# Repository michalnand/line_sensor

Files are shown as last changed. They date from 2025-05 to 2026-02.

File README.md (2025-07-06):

# i2c sensor for line follower

- 10x analog readed sensor
- stm32g031k8u6 64MHz arm cortex m0+ mcu
- i2c interface, with FFC cable
- uart, swdio availible for debug

# photos

TODO

# hardware basic

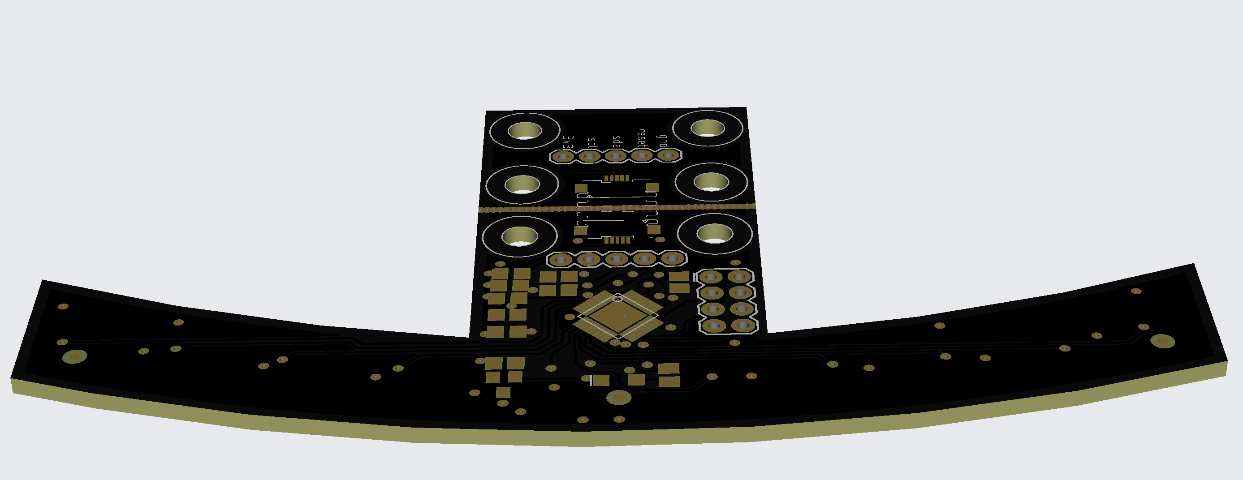
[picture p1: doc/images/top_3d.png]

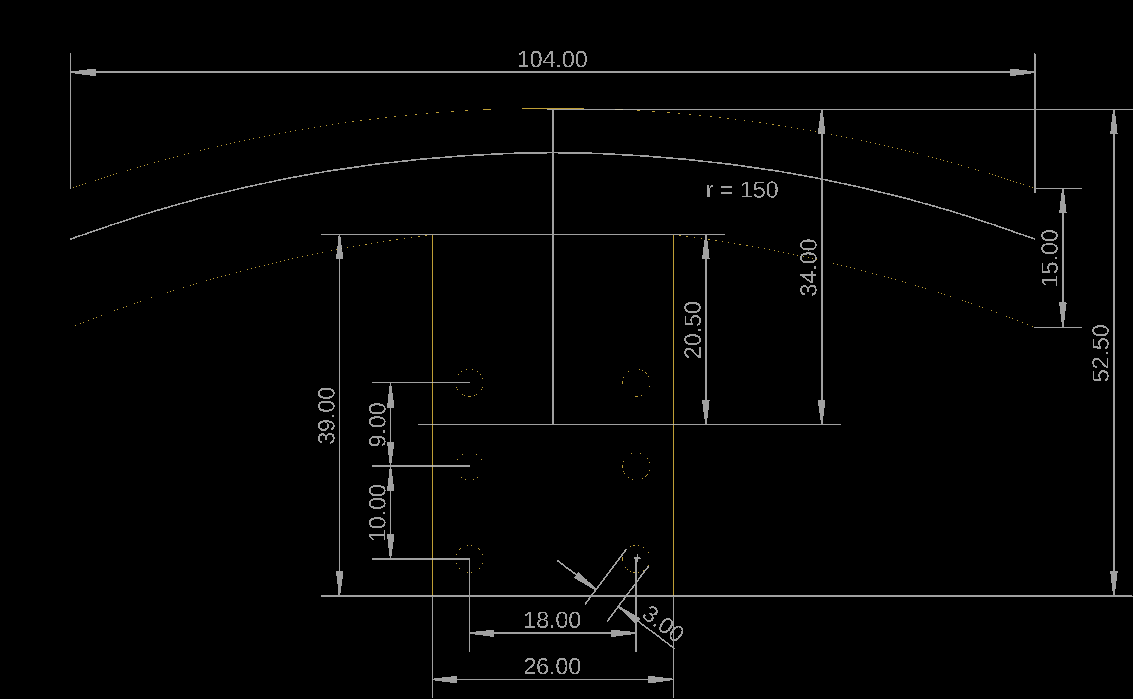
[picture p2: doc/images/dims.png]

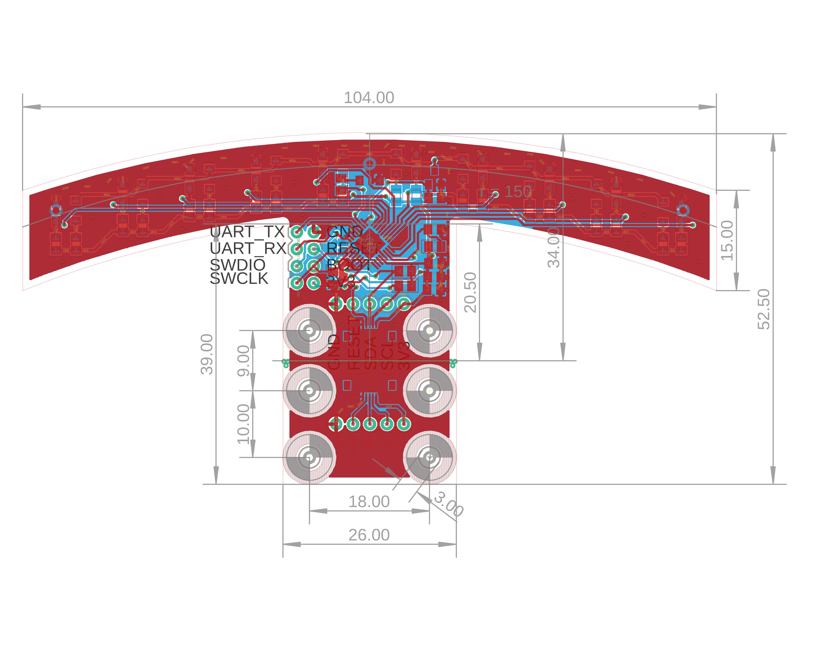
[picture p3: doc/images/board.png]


# hardware slim

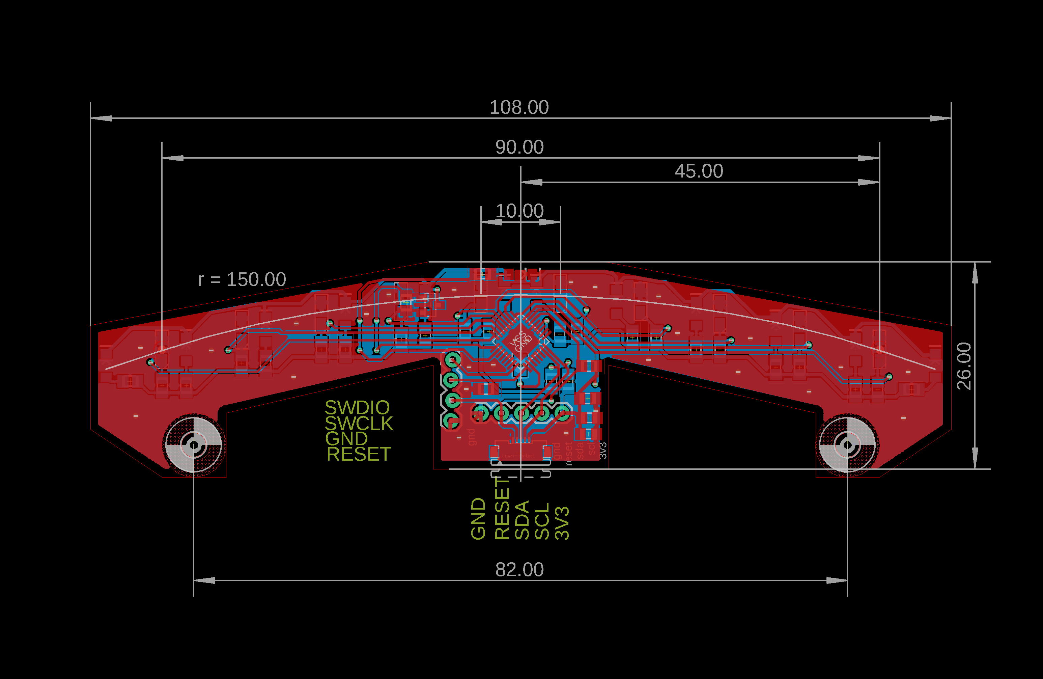
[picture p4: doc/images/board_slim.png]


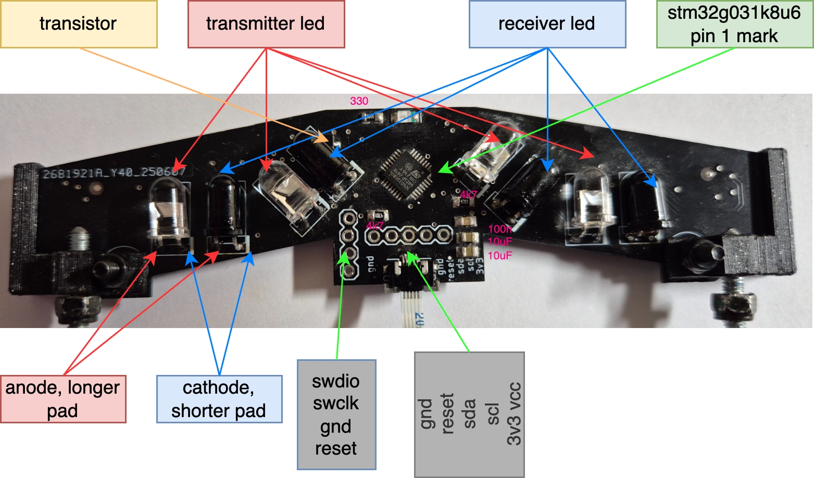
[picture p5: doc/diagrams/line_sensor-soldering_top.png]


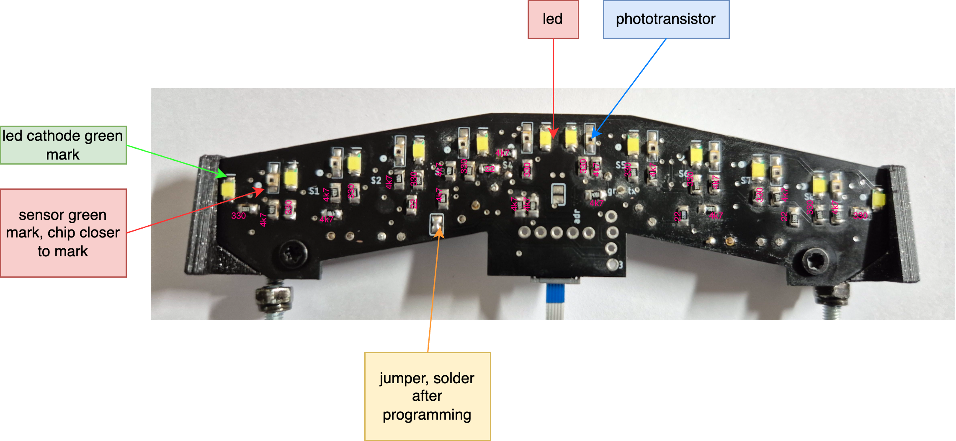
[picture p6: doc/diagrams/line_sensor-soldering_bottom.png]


# arduino example - minimal code

link to file : [demo_code](examples/arduino/minimal_test/minimal_test.ino)

## example output 

- device i2c address is 7bit, 0x42
- in setup, program prints readed  who am I, must be readed as **171** (dec 171) if connected correctly
- program prints LS_DIF_FIL_REG reading : filtered differences of on / off leds readings

```bash
who am i reg : 171
0 6 0 0 598 27 3307 3303 3305 3299 
11 6 0 0 560 3 0 0 0 0 
0 2 2 0 594 86 20 7 0 0 
0 3 4 0 594 87 21 7 1 0 
0 4 2 0 594 88 20 5 1 0 
11 5 0 0 562 0 0 0 0 0 
0 3 4 0 596 87 19 7 2 0 
0 6 4 0 594 86 19 6 2 0 
```

# arduino example - full reading

link to file : [demo_code](examples/arduino/full_test/full_test.ino)

## example output

- device i2c address is 7bit, 0x42
- who am I must be readed as **171** (dec 171)
- readings per second : arround 1800 .. 2000, with 100kHz default arduino i2c speed
- readed data :
  - line 1 : led turned off readings, register LS_RAW_OFF_REG
  - line 2 : led turned in readings, register LS_RAW_ON_REG
  - line 3 : led turned off low pass filtered readings, register LS_FIL_OFF_REG
  - line 4 : led turned in low pass filtered readings, register LS_FIL_ON_REG
  - line 5 : raw readings difference, register LS_DIF_RAW_REG
  - line 6 : filtered readings difference, register LS_DIF_FIL_REG
- in practice, only reading from LS_DIF_FIL_REG (or LS_DIF_RAW_REG) is necessary to estimate line position

```bash
who am i reg : 171
readings per second 2000
readed data
1206 1467 1156 1393 3102 1862 1558 1523 1559 1495 
1206 1464 1139 1365 815 1351 1501 1515 1567 1280 
1205 1467 1152 1390 3087 1851 1552 1520 1556 1494 
1203 1461 1136 1361 810 1349 1501 1515 1563 1280 
7 7 10 36 2253 464 39 1 0 0 
0 6 16 30 2269 543 68 17 3 0 
```

# usage

## compiling firmware

- arm-none-eabi-gcc is required

```bash
cd firmware
make clean
make
```

## writing into flash

- use st-link for write firmware
- connect gnd, swclk, swdio and reset to debug connector
- execture **st-flash --connect-under-reset write build.bin 0x8000000**

```bash
cd firmware/bin
./arm_burn
```

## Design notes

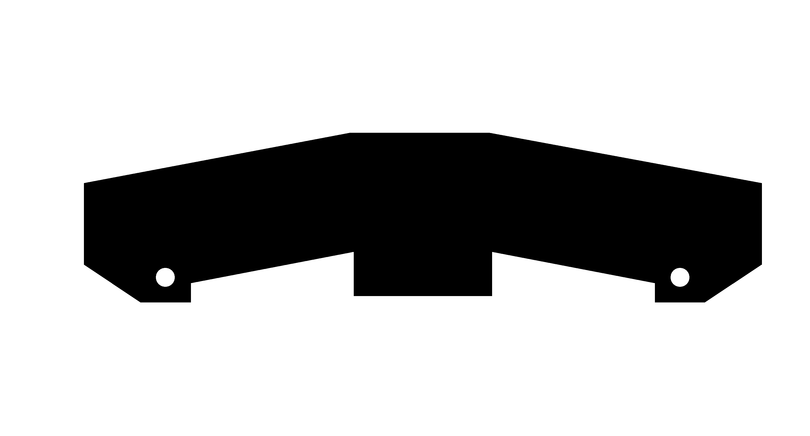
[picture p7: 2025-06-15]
hardware/board_v2/images/board_out_fill.png

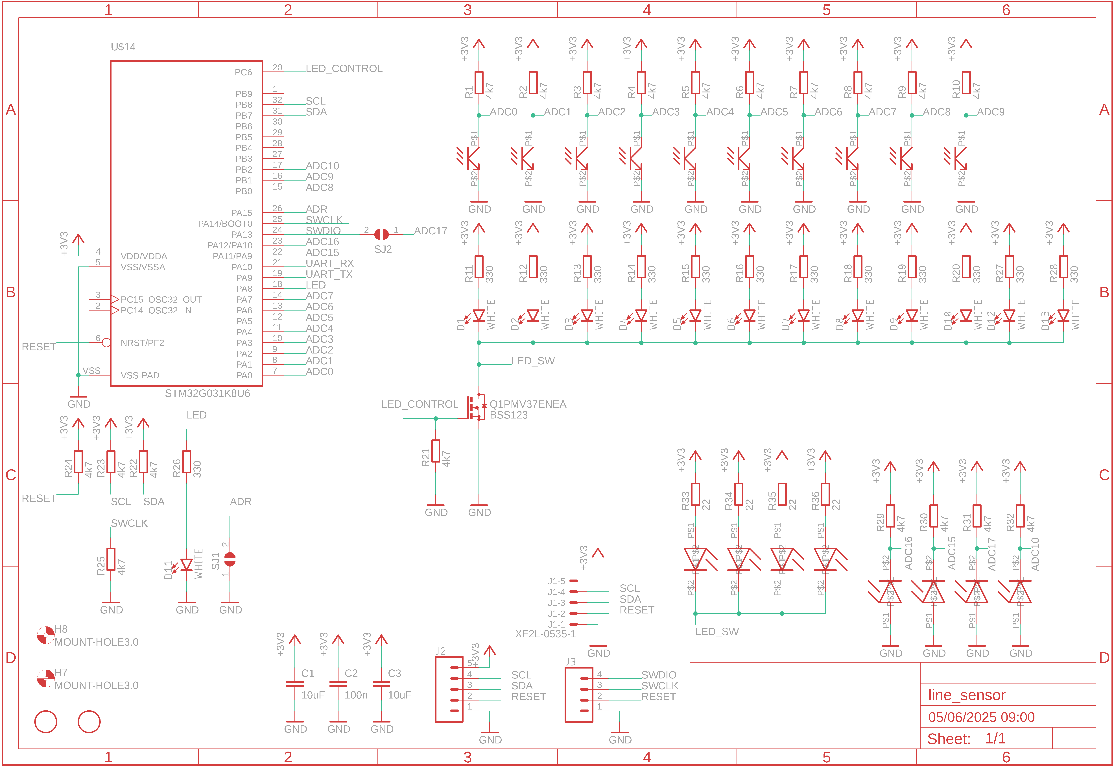
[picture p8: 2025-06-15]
hardware/board_v2/images/schem.png

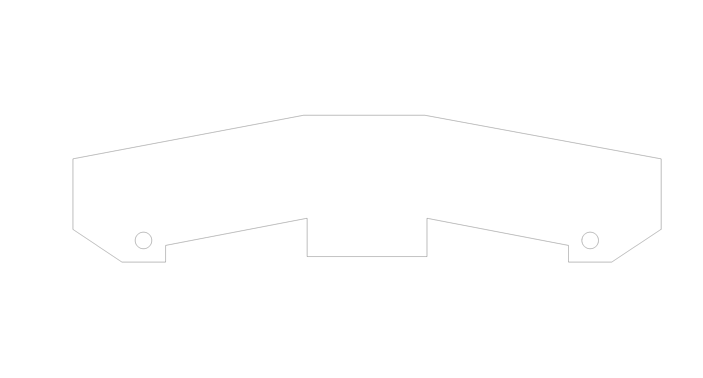
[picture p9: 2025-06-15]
hardware/board_v2/images/board_out.png

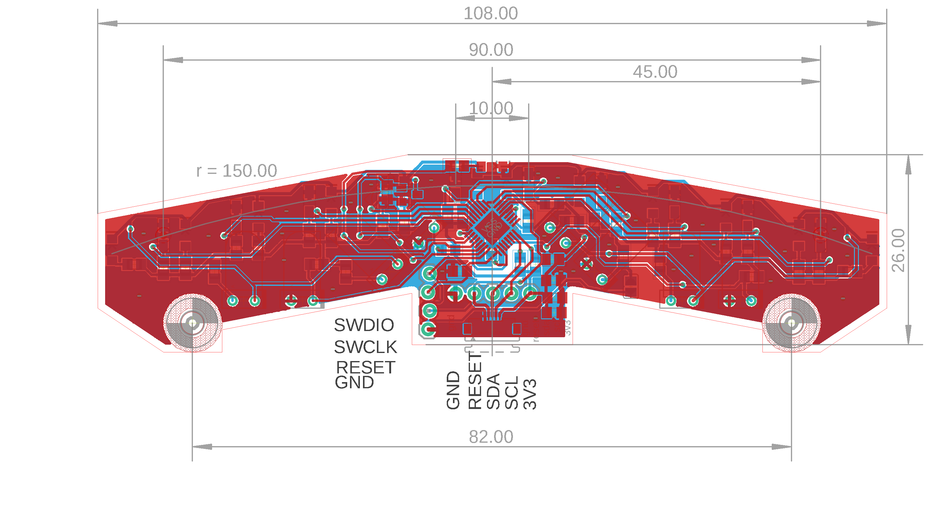
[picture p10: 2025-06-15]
hardware/board_v2/images/board.png

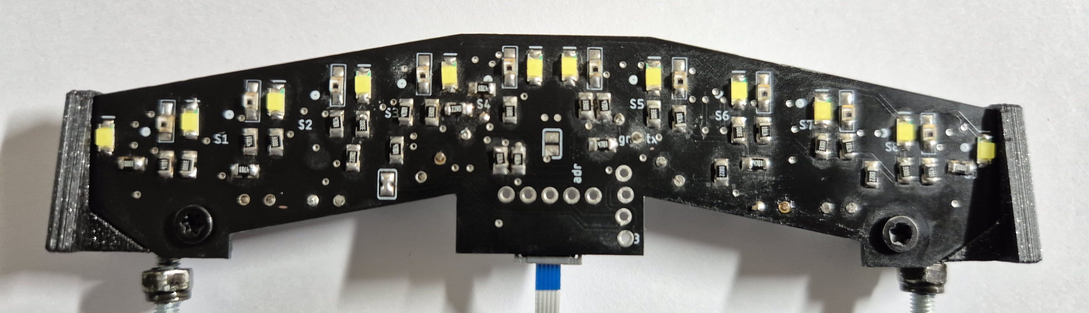
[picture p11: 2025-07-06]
doc/diagrams/bottom.jpg

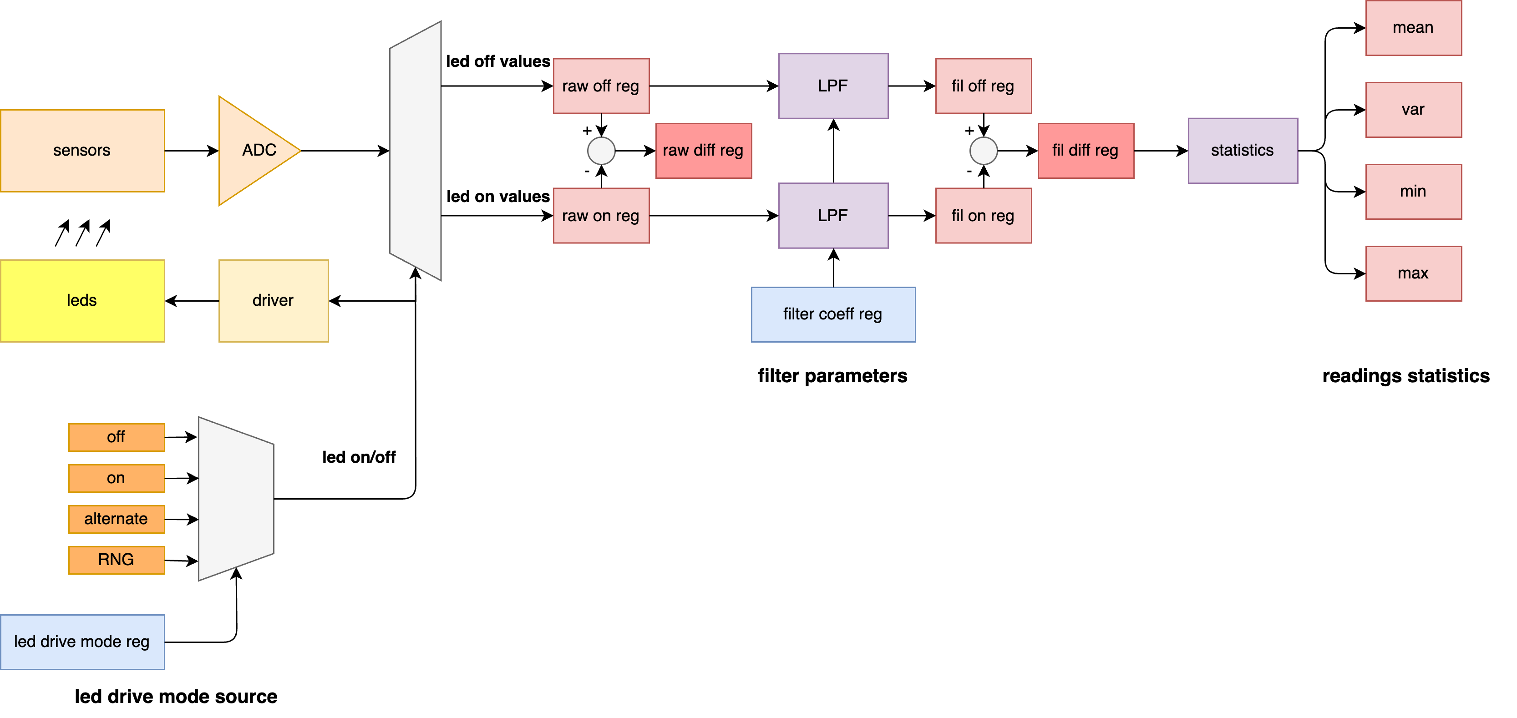
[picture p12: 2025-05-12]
doc/diagrams/line_sensor.png

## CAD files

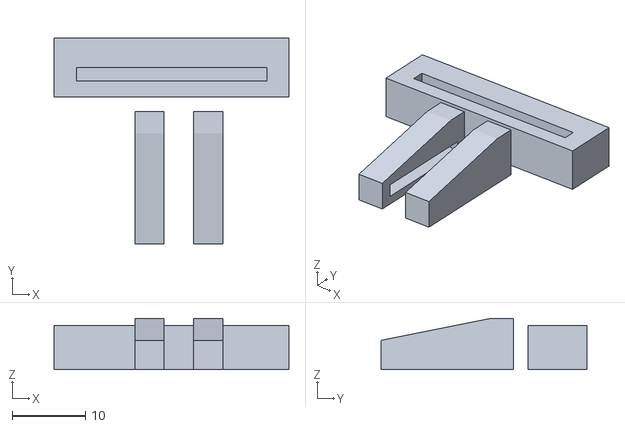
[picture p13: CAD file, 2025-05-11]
hardware/3d_model/line_sensor_3d_parts.stl
32.0 x 28.0 x 7.00

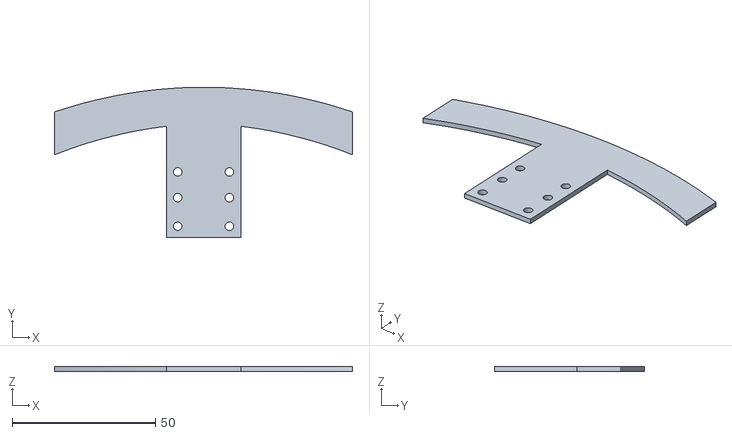
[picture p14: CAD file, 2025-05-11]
hardware/3d_model/line_sensor_model.stl
104.0 x 52.5 x 1.60

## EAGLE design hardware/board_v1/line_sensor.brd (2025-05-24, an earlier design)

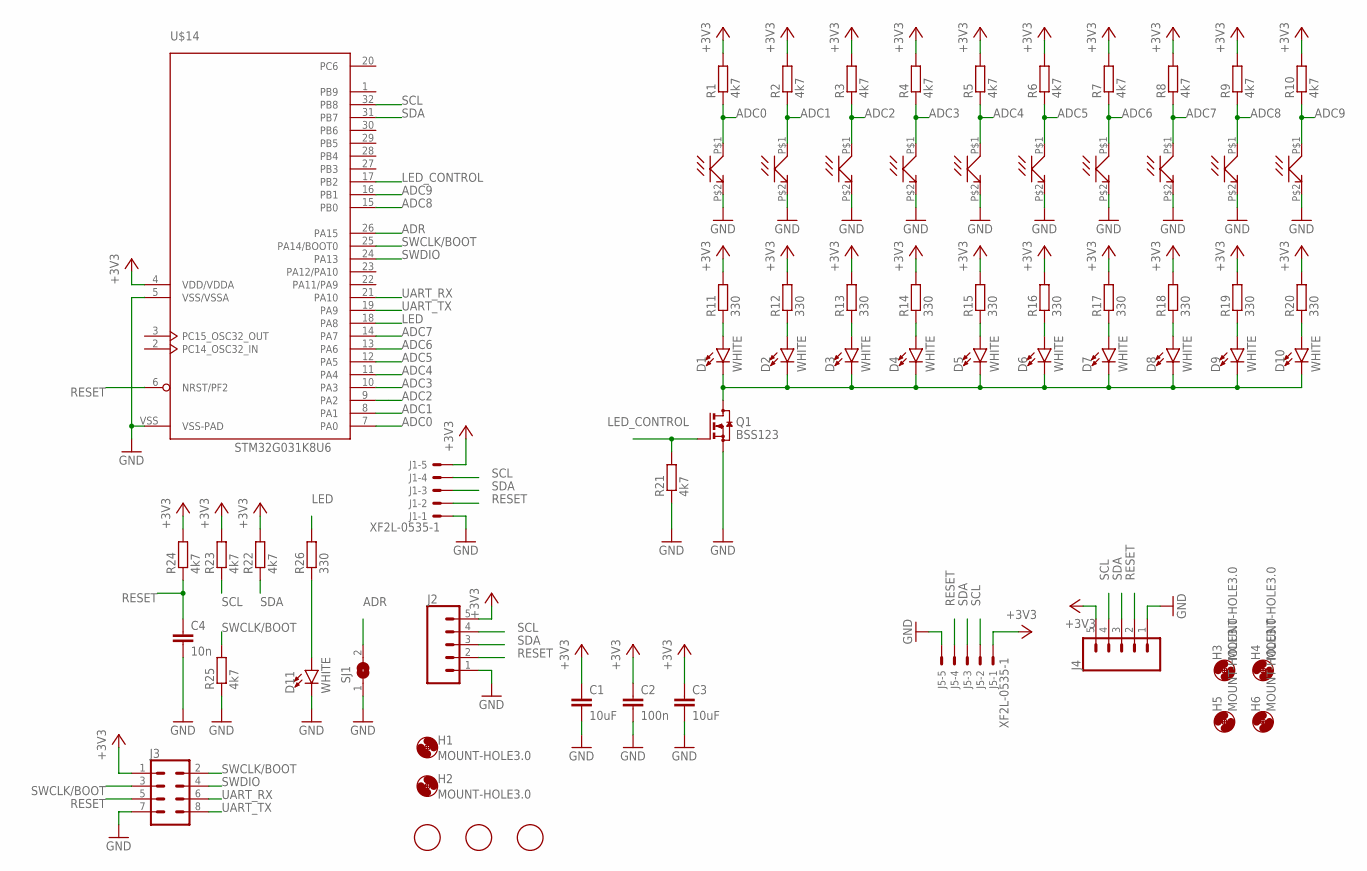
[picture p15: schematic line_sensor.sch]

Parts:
C1, C3: 10uF; C0805K
C2: 100n; C0805K
C4: 10n; C0805K
D1, D2, D3, D4, D5, D6, D7, D8, D9, D10, D11: WHITE; LED-1206
H1, H2, H3, H4, H5, H6: MOUNT-HOLE3.0; 3,0
J1, J5: XF2L-0535-1
J2, J4: CONN_05; 1X05
J3: CONN_04X2; 2X4
Q1: BSS123; SOT23
R1, R2, R3, R4, R5, R6, R7, R8, R9, R10, R21, R22, R23, R24, R25: 4k7; M0805
R11, R12, R13, R14, R15, R16, R17, R18, R19, R20, R26: 330; M0805
SJ1: SJ
U$1, U$2, U$3, U$4, U$5, U$6, U$7, U$8, U$9, U$10: SFH3710; SFH710
U$11, U$12, U$13: FIDUCIAL; FIDUCIAL_1MM
U$14: STM32G031K8U6; UFQFPN32

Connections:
+3V3: C1.1, C2.1, C3.1, J1.5 (MS), J2.5, J3.1, J4.5, J5.1 (MSV), R1.2, R2.2, R3.2, R4.2, R5.2, R6.2, R7.2, R8.2, R9.2, R10.2, R11.2, R12.2, R13.2, R14.2, R15.2, R16.2, R17.2, R18.2, R19.2, R20.2, R22.2, R23.2, R24.2, U$14.4 (VDD/VDDA)
ADC0: R1.1, U$1.P$1 (C), U$14.7 (PA0)
ADC1: R2.1, U$2.P$1 (C), U$14.8 (PA1)
ADC2: R3.1, U$3.P$1 (C), U$14.9 (PA2)
ADC3: R4.1, U$4.P$1 (C), U$14.10 (PA3)
ADC4: R5.1, U$5.P$1 (C), U$14.11 (PA4)
ADC5: R6.1, U$6.P$1 (C), U$14.12 (PA5)
ADC6: R7.1, U$7.P$1 (C), U$14.13 (PA6)
ADC7: R8.1, U$8.P$1 (C), U$14.14 (PA7)
ADC8: R9.1, U$9.P$1 (C), U$14.15 (PB0)
ADC9: R10.1, U$10.P$1 (C), U$14.16 (PB1)
ADR: SJ1.2, U$14.26 (PA15)
GND: C1.2, C2.2, C3.2, C4.2, D11.C, J1.1 (MSV), J2.1, J3.7, J4.1, J5.5 (MS), Q1.2 (S), R21.1, R25.1, SJ1.1, U$1.P$2 (E), U$2.P$2 (E), U$3.P$2 (E), U$4.P$2 (E), U$5.P$2 (E), U$6.P$2 (E), U$7.P$2 (E), U$8.P$2 (E), U$9.P$2 (E), U$10.P$2 (E), U$14.5 (VSS/VSSA), U$14.VSS (VSS-PAD)
LED: R26.2, U$14.18 (PA8)
LED_CONTROL: Q1.1 (G), R21.2, U$14.17 (PB2)
unnamed: D1.A, R11.1
unnamed: D2.A, R12.1
unnamed: D3.A, R13.1
unnamed: D4.A, R14.1
unnamed: D5.A, R15.1
unnamed: D6.A, R16.1
unnamed: D7.A, R17.1
unnamed: D8.A, R18.1
unnamed: D9.A, R19.1
unnamed: D10.A, R20.1
unnamed: D1.C, D2.C, D3.C, D4.C, D5.C, D6.C, D7.C, D8.C, D9.C, D10.C, Q1.3 (D)
unnamed: D11.A, R26.1
RESET: C4.1, J1.2 (MS), J2.2, J3.5, J4.2, J5.4 (MS), R24.1, U$14.6 (NRST/PF2)
SCL: J1.4 (MS), J2.4, J4.4, J5.2 (MS), R23.1, U$14.32 (PB8)
SDA: J1.3 (MS), J2.3, J4.3, J5.3 (MS), R22.1, U$14.31 (PB7)
SWCLK/BOOT: J3.2, J3.3, R25.2, U$14.25 (PA14/BOOT0)
SWDIO: J3.4, U$14.24 (PA13)
UART_RX: J3.6, U$14.21 (PA10)
UART_TX: J3.8, U$14.19 (PA9)

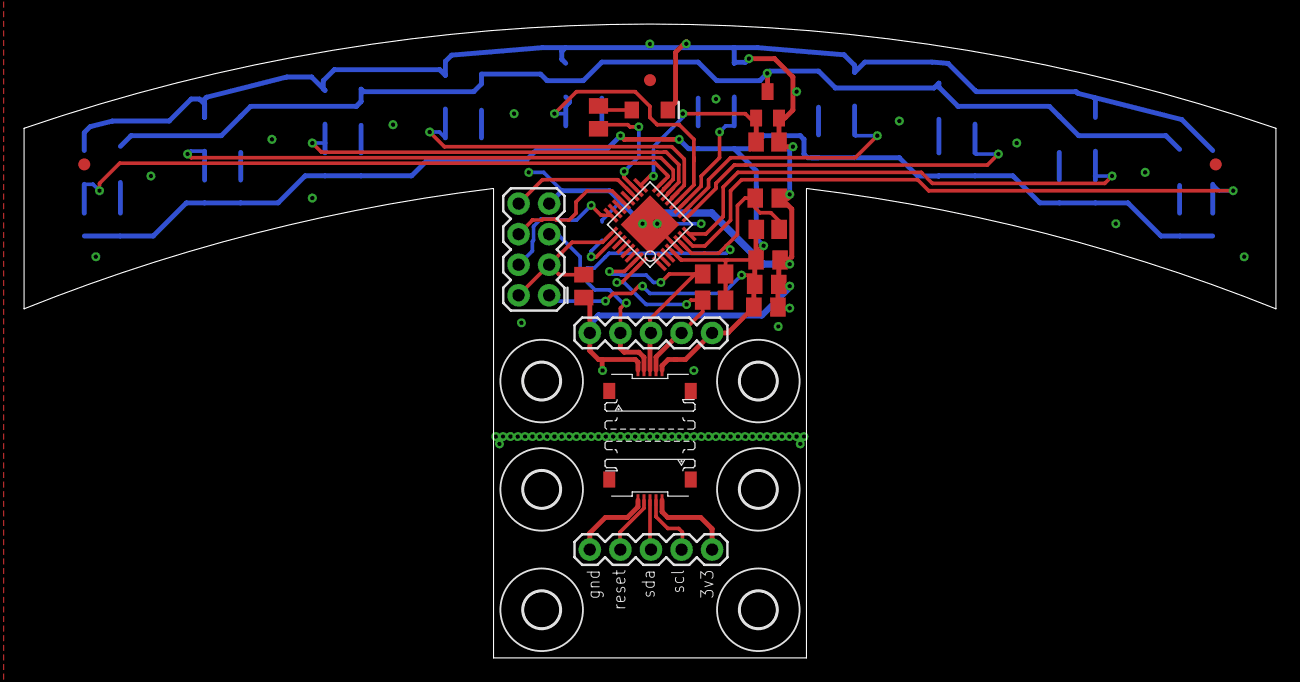
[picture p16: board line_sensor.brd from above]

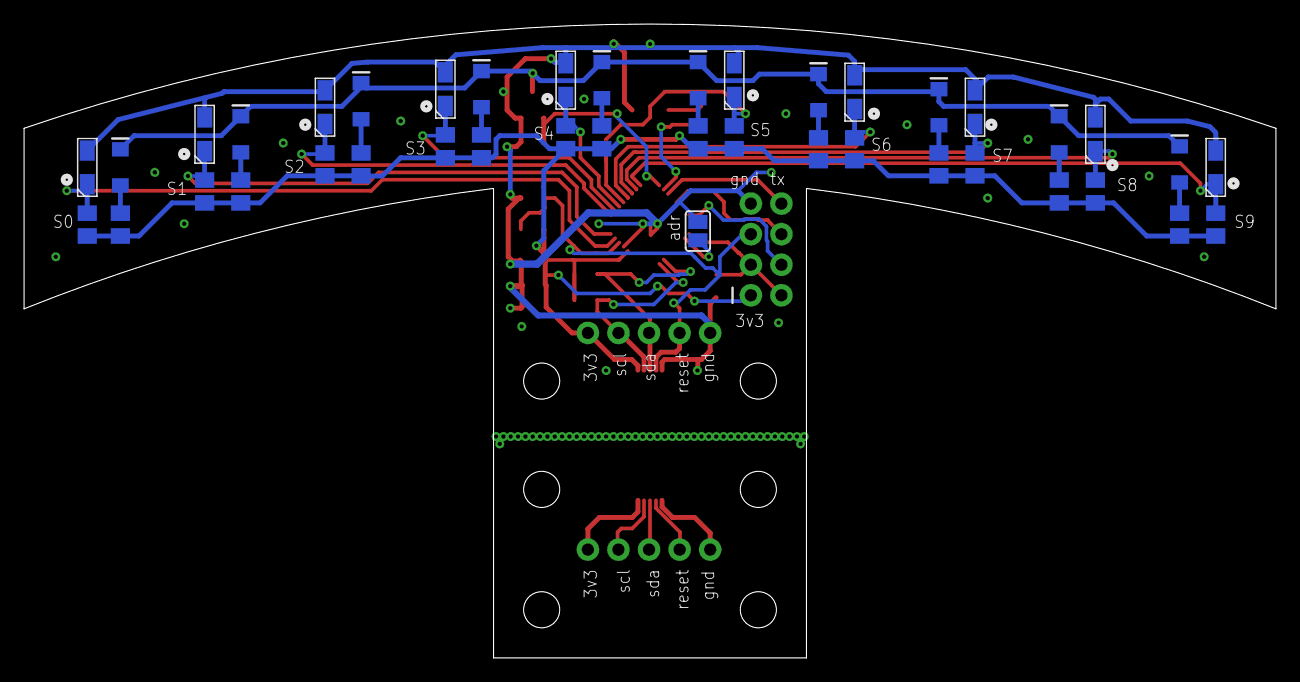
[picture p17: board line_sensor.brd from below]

Board: 2 copper layers, 104.0 x 52.7 mm, 68 parts (41 on the bottom side), 34 nets.

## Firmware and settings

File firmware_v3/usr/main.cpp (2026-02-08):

#include "drivers.h"
#include "common.h"
#include "tmath.h"

#include "i2c_regs.h"
#include "i2c_slave.h"

#include "line_sensor.h"

void update_reg(uint8_t *dest_ptr, uint8_t reg_adr, uint16_t value)
{
    uint8_t res_h = (value>>8)&0xff;
    uint8_t res_l = (value>>0)&0xff;    

    // update must be atomic
    __disable_irq();    
    dest_ptr[reg_adr + 0] = res_h;
    dest_ptr[reg_adr + 1] = res_l;
    __enable_irq(); 
}

void update_regs(uint8_t *dest_ptr, uint32_t dest_adr, int16_t *source)
{
    for (unsigned int i = 0; i < SENSORS_COUNT; i++)
    {
        uint16_t tmp = source[i];  
        update_reg(dest_ptr, 2*i + dest_adr, tmp);
    }
}



int16_t compute_mean(int16_t *values)
{   
    int32_t result = 0;

    for (unsigned int i = 0; i < SENSORS_COUNT; i++)
    {
        __disable_irq();
        int16_t tmp = values[i];
        __enable_irq(); 

        result+= tmp;
    }

    result = result/(int32_t)SENSORS_COUNT;

    return result;
}


int main() 
{       
    drivers_init();   

    Gpio<'A', 8, GPIO_MODE_OUT> led;
    led = 0;

    
    
    LineSensor line_sensor;
    line_sensor.init();
    line_sensor.set_filter(7);
    

    
    I2CSlave i2c;
    i2c.init();

    
    i2c.buffer[LS_WHOAMI_REG]  = WHO_AM_I_VALUE; 
    i2c.buffer[LS_FILTER_REG]  = 7;  
    
    // fill testing data, 1001, 2002, 3003 ... 14014
    for (unsigned int i = 0; i < LS_DATA_SIZE; i++)
    {
        update_reg(i2c.buffer, LS_TEST_DAT_REG + 2*i, 1000*(i+1) + (i + 1));
    }


    while (1)
    {   

        /*
        if (i2c.is_write_flag())
        {
            uint8_t mode = i2c.buffer[LS_CONFIG0_REG];

            if (mode == LED_OFF)
            {
                line_sensor.set_mode(LED_OFF);
            }
            else if (mode == LED_ON)
            {
                line_sensor.set_mode(LED_ON);
            }
            else if (mode == LED_ALTERNATE)
            {
                line_sensor.set_mode(LED_ALTERNATE);
            }
            else 
            {
                line_sensor.set_mode(LED_RNG);
            }

            uint8_t filter = i2c.buffer[LS_FILTER_REG];
            line_sensor.set_filter(filter);
        }
        */
        
        // refresh data
        update_regs(i2c.buffer, LS_RAW_OFF_REG, line_sensor.led_off_result);
        update_regs(i2c.buffer, LS_RAW_ON_REG,  line_sensor.led_on_result);
        
        update_regs(i2c.buffer, LS_FIL_OFF_REG, line_sensor.led_off_fil_result);
        update_regs(i2c.buffer, LS_FIL_ON_REG,  line_sensor.led_on_fil_result);
  
        update_regs(i2c.buffer, LS_DIF_RAW_REG, line_sensor.led_dif_result);
        update_regs(i2c.buffer, LS_DIF_FIL_REG, line_sensor.led_dif_fil_result);
        


        // refresh statistics   
        // update_reg(i2c.buffer, LS_STATS_0_REG, line_sensor.mean_result);
        // update_reg(i2c.buffer, LS_STATS_1_REG, line_sensor.var_result);
        // update_reg(i2c.buffer, LS_STATS_2_REG, line_sensor.min_result);
        // update_reg(i2c.buffer, LS_STATS_3_REG, line_sensor.max_result);

        // wait for next event
        __asm("wfi");
    }
    

    return 0;
}

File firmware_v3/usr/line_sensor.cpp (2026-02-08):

#include "line_sensor.h"



#ifdef __cplusplus
extern "C" {
#endif

LineSensor *g_line_sensor;


void ADC1_IRQHandler(void) 
{
    if (LL_ADC_IsActiveFlag_EOC(ADC1))
    {
        uint32_t value = LL_ADC_REG_ReadConversionData12(ADC1);
        LL_ADC_ClearFlag_EOC(ADC1);

        uint32_t next_channel = g_line_sensor->callback(value);

        // Change channel for next conversion
        ADC1->CHSELR = next_channel;

        // Start new conversion
        LL_ADC_REG_StartConversion(ADC1);
    }
}

#ifdef __cplusplus
}
#endif

LineSensor::LineSensor()
{

}

void LineSensor::init()
{
    g_line_sensor = this;

    this->channels_map[0] = ADC_CHSELR_CHSEL0;
    this->channels_map[1] = ADC_CHSELR_CHSEL1;
    this->channels_map[2] = ADC_CHSELR_CHSEL2;
    this->channels_map[3] = ADC_CHSELR_CHSEL3;
    this->channels_map[4] = ADC_CHSELR_CHSEL4;
    this->channels_map[5] = ADC_CHSELR_CHSEL5;
    this->channels_map[6] = ADC_CHSELR_CHSEL6;
    this->channels_map[7] = ADC_CHSELR_CHSEL7;
    this->channels_map[8] = ADC_CHSELR_CHSEL8;
    this->channels_map[9] = ADC_CHSELR_CHSEL9;

    this->channels_map[10] = ADC_CHSELR_CHSEL16;
    this->channels_map[11] = ADC_CHSELR_CHSEL15;
    this->channels_map[12] = ADC_CHSELR_CHSEL17;
    this->channels_map[13] = ADC_CHSELR_CHSEL10;

   
    this->_init_vars();

    this->_gpio_init(); 

    
    this->_adc_init();
    this->_nvic_init();

   
    
    // select first channel
    ADC1->CHSELR = this->channels_map[0];

    // Start first conversion
    LL_ADC_REG_StartConversion(ADC1);
}


void LineSensor::set_filter(uint8_t value)
{   
    this->filter_coeff = value;
}


uint32_t LineSensor::callback(int32_t value)
{
    // initial state
    if (this->state == 0)
    {
        // toogle LED
        // turn on or off led, depending on state
        if (this->led_state == true)
        {
            this->led_state = false;
            this->led_control = 0;
        }
        
        else
        {
            this->led_state = true;
            this->led_control = 1;
        }
       
        // initial state for next round 
        this->channel       = 0;
        this->state         = 1;
        
        // here we can process previous results, and adds some delay for led state change
        this->_processing();
    }
    // waiting states, optional, for led settling time
    else if (this->state < SENSORS_WAIT_STATES)
    {
        this->state++;
    }

    // read channels state  
    else
    {
        // store results to corresponding register
        if (this->led_state)
        {
            this->led_on_result[this->channel] = value;
        }
        else
        {
            this->led_off_result[this->channel] = value;
        }   
        
        // we returns next channel for ADC to read
        this->channel++;    

        // reading done, reset state and channel for next round
        if (this->channel >= SENSORS_COUNT)
        {   
            this->state   = 0;
            this->channel = 0;
        }
    }
    
    // return next channel for ADC to read
    return this->channels_map[this->channel];
}



void LineSensor::_init_vars()
{
    this->led_control   = 0;
    
    this->state         = 0;
    this->led_state     = false;
    this->channel       = 0;
    this->filter_coeff  = 7;    


    for (unsigned int i = 0; i < SENSORS_COUNT; i++)
    {
        this->led_off_result[i]     = 4096;
        this->led_on_result[i]      = 0;

        this->led_off_fil_result[i] = 4096;
        this->led_on_fil_result[i]  = 0;

        this->led_dif_result[i]     = 0;
        this->led_dif_fil_result[i] = 0;
    }
}

void LineSensor::_gpio_init(void) 
{
    // Enable GPIOA and GPIOB clocks for ADC channels
    LL_IOP_GRP1_EnableClock(LL_IOP_GRP1_PERIPH_GPIOA);
    LL_IOP_GRP1_EnableClock(LL_IOP_GRP1_PERIPH_GPIOB);
    LL_IOP_GRP1_EnableClock(LL_IOP_GRP1_PERIPH_GPIOC);

        
    // Configure PA0 - PA7 as analog (ADC_IN0 to ADC_IN7)
    LL_GPIO_SetPinMode(GPIOA, LL_GPIO_PIN_0, LL_GPIO_MODE_ANALOG);
    LL_GPIO_SetPinPull(GPIOA, LL_GPIO_PIN_0, LL_GPIO_PULL_NO);

    LL_GPIO_SetPinMode(GPIOA, LL_GPIO_PIN_1, LL_GPIO_MODE_ANALOG);
    LL_GPIO_SetPinPull(GPIOA, LL_GPIO_PIN_1, LL_GPIO_PULL_NO);

    LL_GPIO_SetPinMode(GPIOA, LL_GPIO_PIN_2, LL_GPIO_MODE_ANALOG);
    LL_GPIO_SetPinPull(GPIOA, LL_GPIO_PIN_2, LL_GPIO_PULL_NO);

    LL_GPIO_SetPinMode(GPIOA, LL_GPIO_PIN_3, LL_GPIO_MODE_ANALOG);
    LL_GPIO_SetPinPull(GPIOA, LL_GPIO_PIN_3, LL_GPIO_PULL_NO);

    LL_GPIO_SetPinMode(GPIOA, LL_GPIO_PIN_4, LL_GPIO_MODE_ANALOG);
    LL_GPIO_SetPinPull(GPIOA, LL_GPIO_PIN_4, LL_GPIO_PULL_NO);

    LL_GPIO_SetPinMode(GPIOA, LL_GPIO_PIN_5, LL_GPIO_MODE_ANALOG);
    LL_GPIO_SetPinPull(GPIOA, LL_GPIO_PIN_5, LL_GPIO_PULL_NO);

    LL_GPIO_SetPinMode(GPIOA, LL_GPIO_PIN_6, LL_GPIO_MODE_ANALOG);
    LL_GPIO_SetPinPull(GPIOA, LL_GPIO_PIN_6, LL_GPIO_PULL_NO);

    LL_GPIO_SetPinMode(GPIOA, LL_GPIO_PIN_7, LL_GPIO_MODE_ANALOG);
    LL_GPIO_SetPinPull(GPIOA, LL_GPIO_PIN_7, LL_GPIO_PULL_NO);  

    // Configure PB0, PB1 as analog (ADC_IN8, ADC_IN9)
    LL_GPIO_SetPinMode(GPIOB, LL_GPIO_PIN_0, LL_GPIO_MODE_ANALOG);
    LL_GPIO_SetPinPull(GPIOB, LL_GPIO_PIN_0, LL_GPIO_PULL_NO);

    LL_GPIO_SetPinMode(GPIOB, LL_GPIO_PIN_1, LL_GPIO_MODE_ANALOG);
    LL_GPIO_SetPinPull(GPIOB, LL_GPIO_PIN_1, LL_GPIO_PULL_NO);


    // Configure PA11, PA12, PA13 as analog (ADC_IN15, ADC_IN16, ADC_IN17)
    LL_GPIO_SetPinMode(GPIOA, LL_GPIO_PIN_11, LL_GPIO_MODE_ANALOG);
    LL_GPIO_SetPinPull(GPIOA, LL_GPIO_PIN_11, LL_GPIO_PULL_NO);
    
    LL_GPIO_SetPinMode(GPIOA, LL_GPIO_PIN_12, LL_GPIO_MODE_ANALOG);
    LL_GPIO_SetPinPull(GPIOA, LL_GPIO_PIN_12, LL_GPIO_PULL_NO);

    LL_GPIO_SetPinMode(GPIOA, LL_GPIO_PIN_13, LL_GPIO_MODE_ANALOG);
    LL_GPIO_SetPinPull(GPIOA, LL_GPIO_PIN_13, LL_GPIO_PULL_NO);

    // Configure PB2 as analog (ADC_IN10)   
    LL_GPIO_SetPinMode(GPIOB, LL_GPIO_PIN_2, LL_GPIO_MODE_ANALOG);
    LL_GPIO_SetPinPull(GPIOB, LL_GPIO_PIN_2, LL_GPIO_PULL_NO);

}
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

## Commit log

2025-05-11 adc + filter
2025-05-11 led modulation modes
2025-05-11 3d parts
    [line_sensor.brd, line_sensor_3d_parts.stl, line_sensor_model.stl]
2025-05-14 adc bug fix
    [robot.brd, robot.sch]
2025-05-18 i2c slave - bugs on stm32f0
    [line_sensor.brd, line_sensor.sch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]
2025-05-24 new hw, firmware for stm32g031
    [line_sensor.brd, line_sensor.sch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]
2025-05-24 adc running
2025-05-26 i2c slave
    [line_sensor.brd, line_sensor.sch]
2025-05-27 i2c bug fixed
2025-05-27 arduino example
2025-05-28 working firmware v1
    [line_sensor.brd, line_sensor.sch]
2025-05-31 demo codes, cleaned up
    [line_sensor.brd, line_sensor.sch, robot.brd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]
2025-06-15 updated v2 firmware
    [line_sensor.brd, line_sensor.sch, line_sensor_3d_parts.stl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]

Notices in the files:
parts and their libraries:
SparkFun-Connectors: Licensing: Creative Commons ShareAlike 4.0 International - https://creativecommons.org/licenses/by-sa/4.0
